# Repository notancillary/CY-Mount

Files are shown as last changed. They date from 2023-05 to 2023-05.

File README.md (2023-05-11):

# CY-Mount
SteamVR Base Station Damage-Free Wall mounts <br>
<br>
A Base staton mount that doesnt require drilling or damaging your walls.<br>
These mounts use standard Command Large strips and provide a very strong/secure vibration free mount for your base stations. <br>
<br>
BOM:<br>
1. 1x  1/4-20 x 1/2" long screw (such as https://www.amazon.com/Powlankou-Pieces-Button-Socket-Stainless/dp/B07ZSXD89C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)<br>
2. 70g PLA / PETG filament<br>
3. 1x Nodrill SVRBS Backplate print<br>
4. 1x 0-40 deg (as needed) SVRBS Bracket print<br>
5. 5x Pairs Large Command strips (i strongly suggest the velcro ones https://www.amazon.com/Command-Picture-Christmas-Decorations-Adhesive/dp/B0B3SBD6RR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)<br>
<br>
 <br><br>
 <br><br>
 <br><br>
 <br><br>
 <br><br>
 <br><br>
<br>
Printing:<br>
<br>
Print settings are as follows:<br>
0.28 layer height<br>
0.4mm nozzle<br>
5 walls<br>
40% infill<br>
<br>
Print in the following orientations.<br>
<br><br>
<br><br>

<br><br>

Assembly:<br>
1. Slide the bracket of choice into the backplate. This connection will be very tight; i suggest using the endge of a table to assist assembly. You will hear a loud click and all parts will be flush when it is fully seated. <br><br>
<br><br>
<br><br>

2. Attach 5x large command strip pairs to the rear of the backplate. Arrange them to be centered on each of the beams. <br><br>

3. Firmly press the assembly against the wall for at least 30 seconds. <br><br>

4. Mount your base station, set angle and attach the 1/4-20 x 1/2" screw. <br><br>

<br><br>

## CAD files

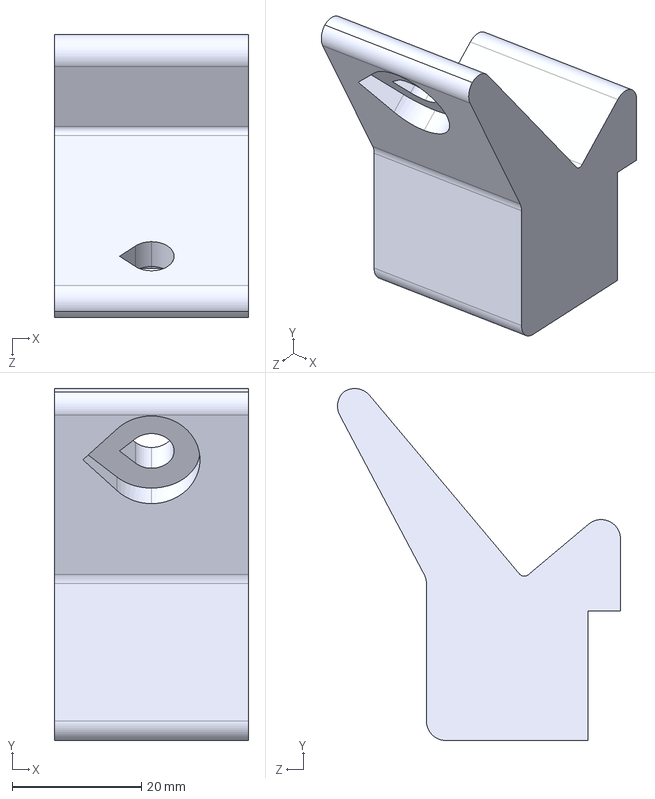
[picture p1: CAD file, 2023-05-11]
40deg SVRBS Bracket.STEP
30.0 x 54.4 x 43.8 mm

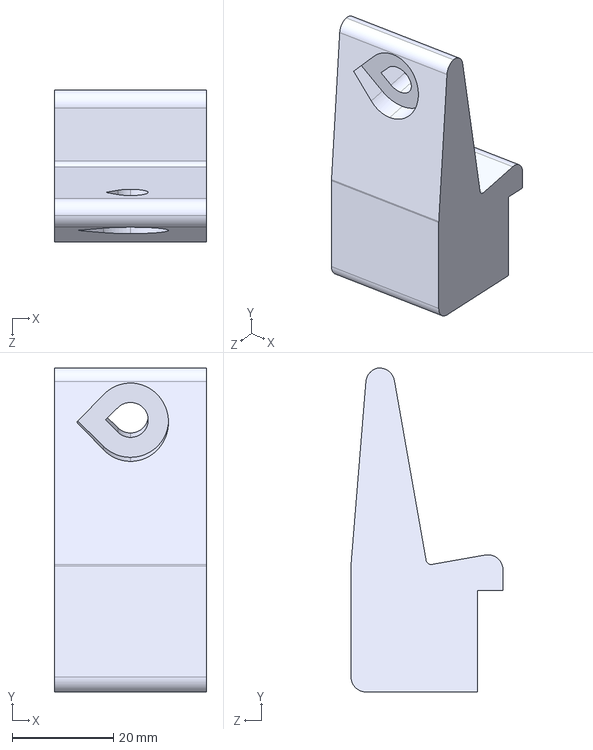
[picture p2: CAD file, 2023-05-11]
10deg SVRBS Bracket.STEP
30.0 x 63.9 x 30.0 mm

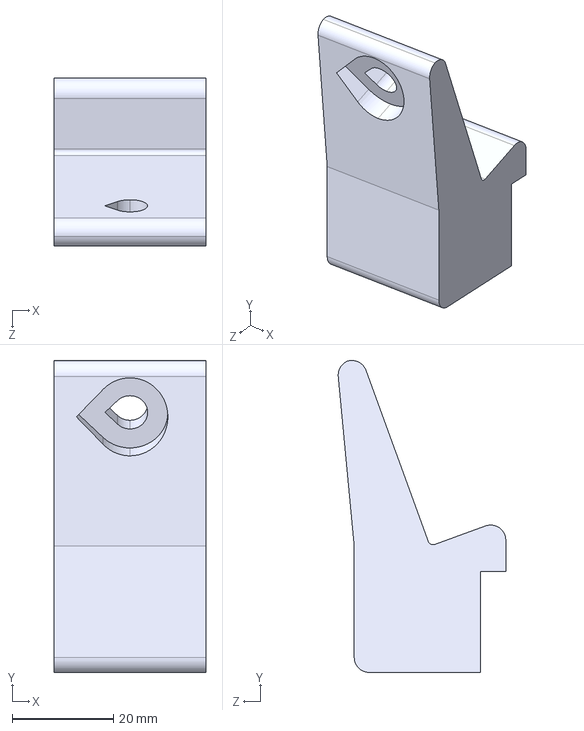
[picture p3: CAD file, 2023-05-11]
20deg SVRBS Bracket.STEP
30.0 x 61.7 x 33.2 mm

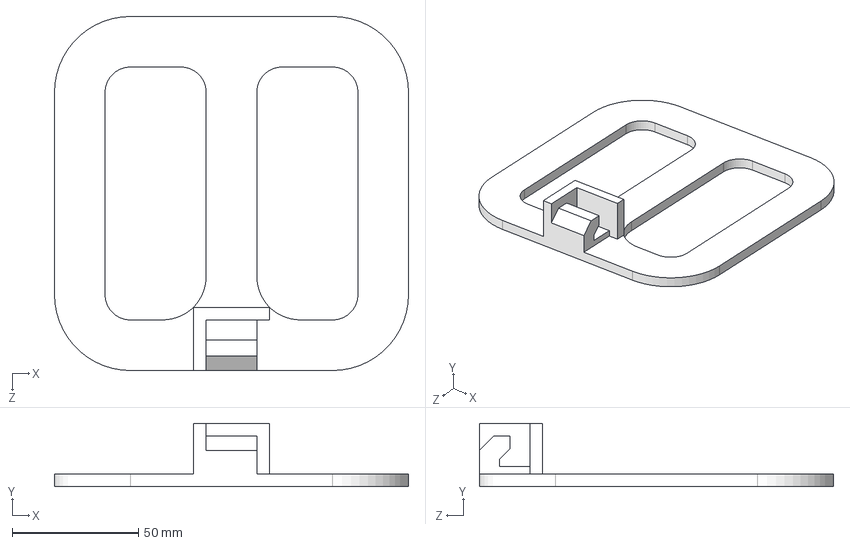
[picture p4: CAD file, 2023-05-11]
Nodrill SVRBS Backplate.STEP
140.0 x 25.0 x 140.0 mm

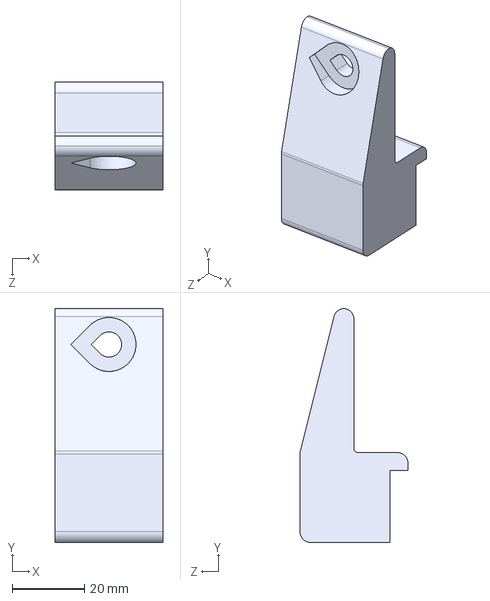
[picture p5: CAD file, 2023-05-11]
0deg SVRBS Bracket.STEP
30.0 x 65.0 x 30.0 mm

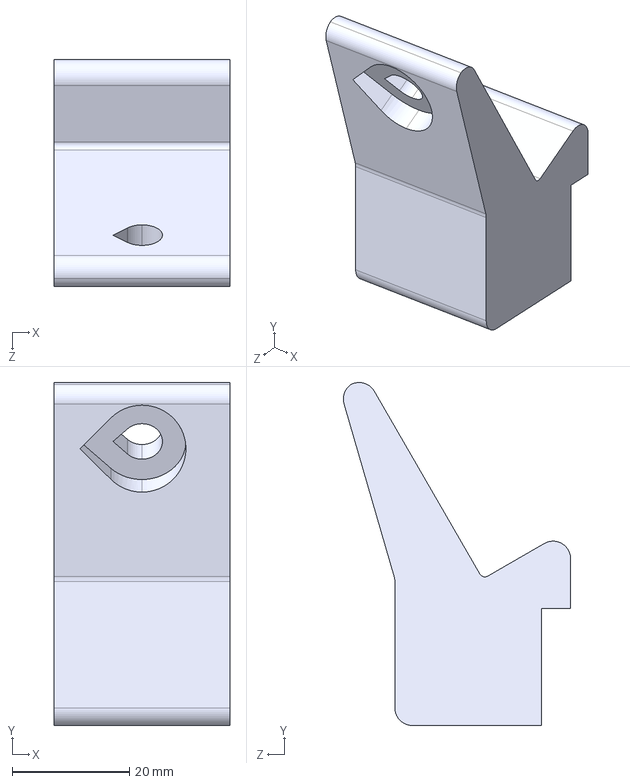
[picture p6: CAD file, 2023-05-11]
30deg SVRBS Bracket.STEP
30.0 x 58.5 x 38.8 mm

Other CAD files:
0deg SVRBS Bracket.STL
10deg SVRBS Bracket.STL
20deg SVRBS Bracket.STL
30deg SVRBS Bracket.STL
40deg SVRBS Bracket.STL
Nodrill SVRBS Backplate.STL
